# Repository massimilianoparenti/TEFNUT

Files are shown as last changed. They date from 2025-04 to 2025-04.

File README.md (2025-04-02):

# TEFNUT
Open-source, low-power temperature, humidity, and VOC sensor with E-Ink display and LoRa connectivity. Battery-powered and designed for both indoor and outdoor use, this device is ideal for smart homes, IoT applications, and environmental monitoring. Easy deployment, high efficiency, and full customization.

**DESCRIPTION**

This project aims to create a simple, low-power temperature, humidity, and VOC sensor with long-range connectivity. At its core, it features an E-Ink display for excellent readability even in direct sunlight, while LoRa communication ensures seamless integration with home automation systems and other IoT applications.

Powered by a battery, this device is built for versatility and easy deployment in both indoor and outdoor environments. It focuses on efficiency and simplicity to provide an accessible and practical solution for monitoring temperature, humidity, air quality, and gas presence.

Best of all, it’s fully open source—anyone can modify, improve, or adapt it to their needs.

If this sounds interesting, stay tuned for updates!

**REPOSITORY MAP**

**CONTRIBUTORS**

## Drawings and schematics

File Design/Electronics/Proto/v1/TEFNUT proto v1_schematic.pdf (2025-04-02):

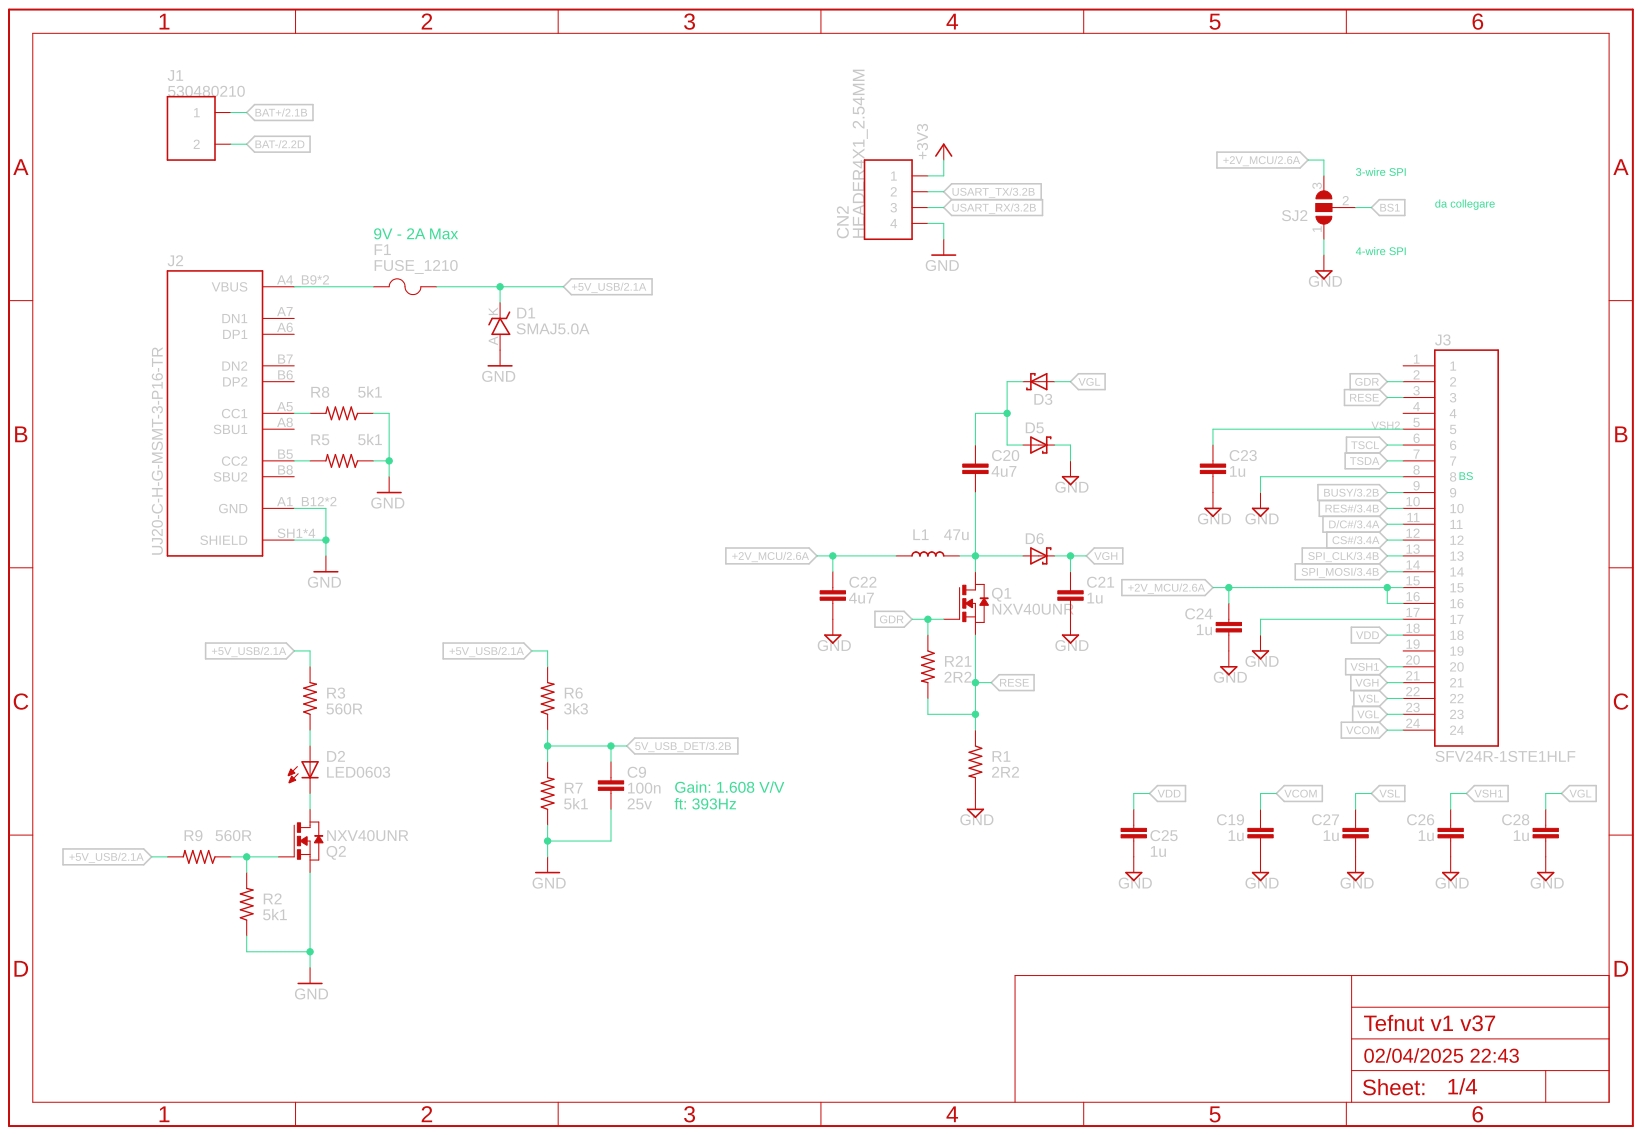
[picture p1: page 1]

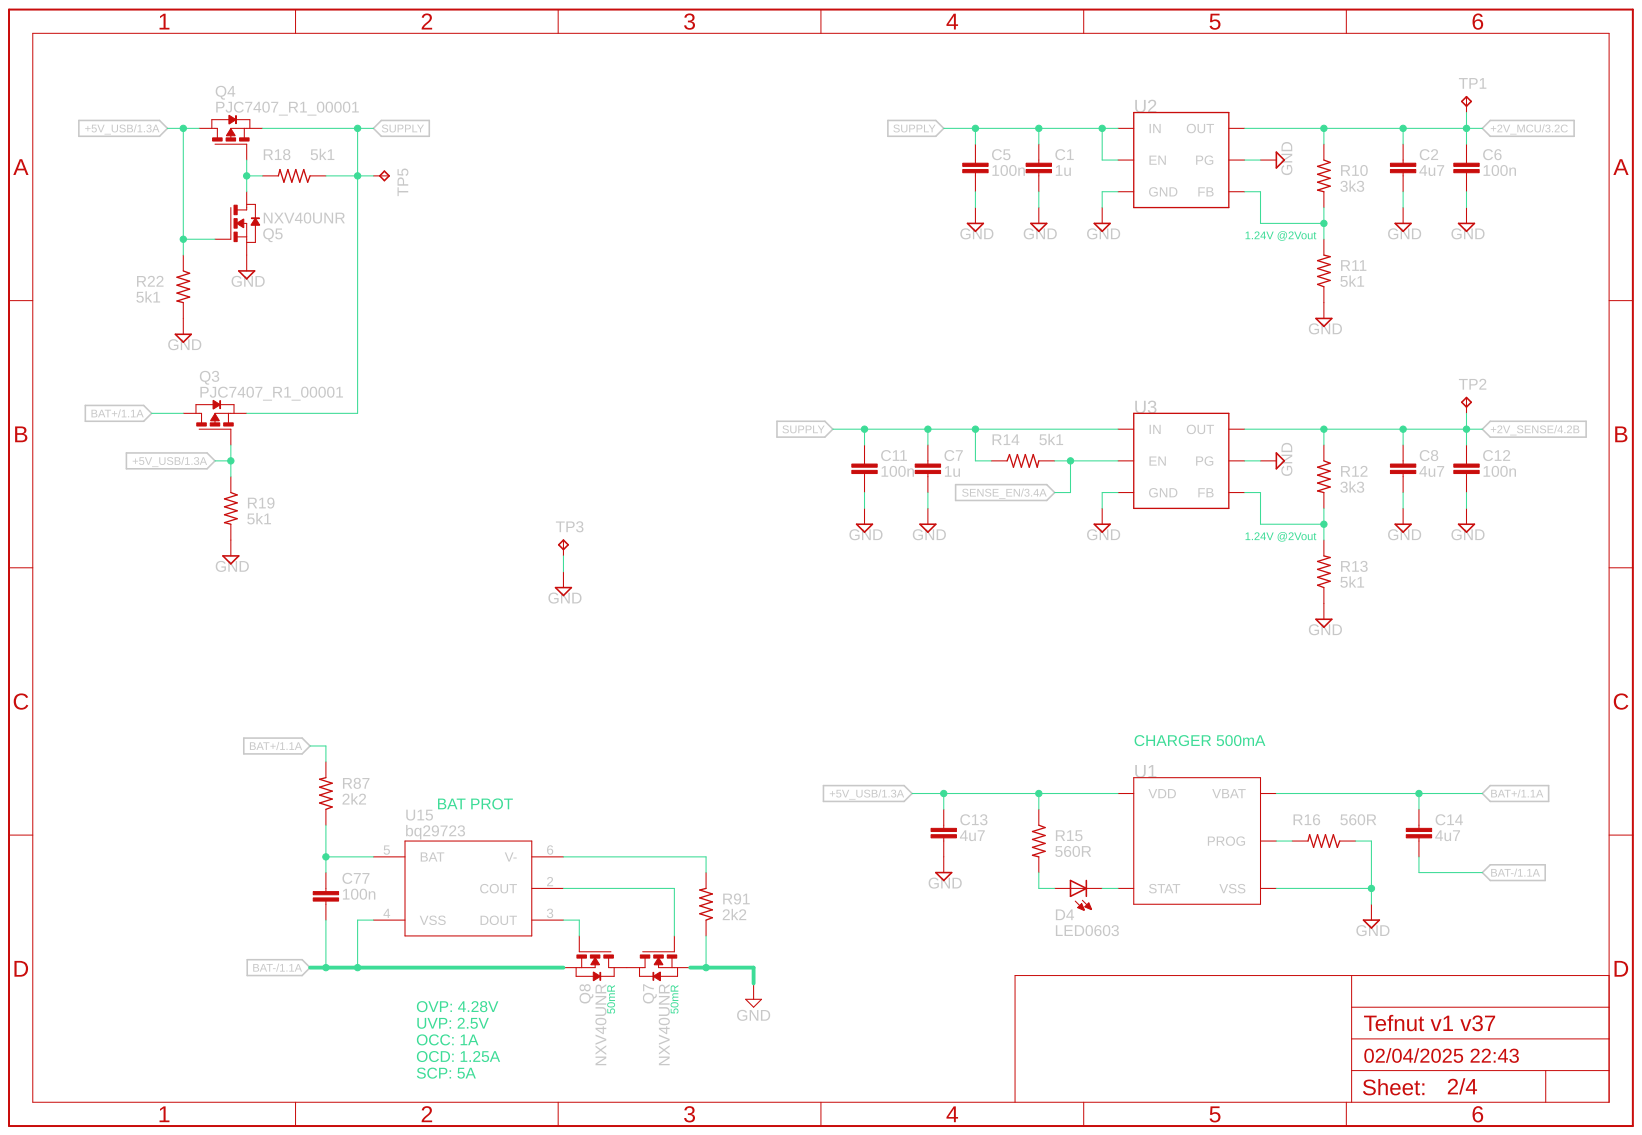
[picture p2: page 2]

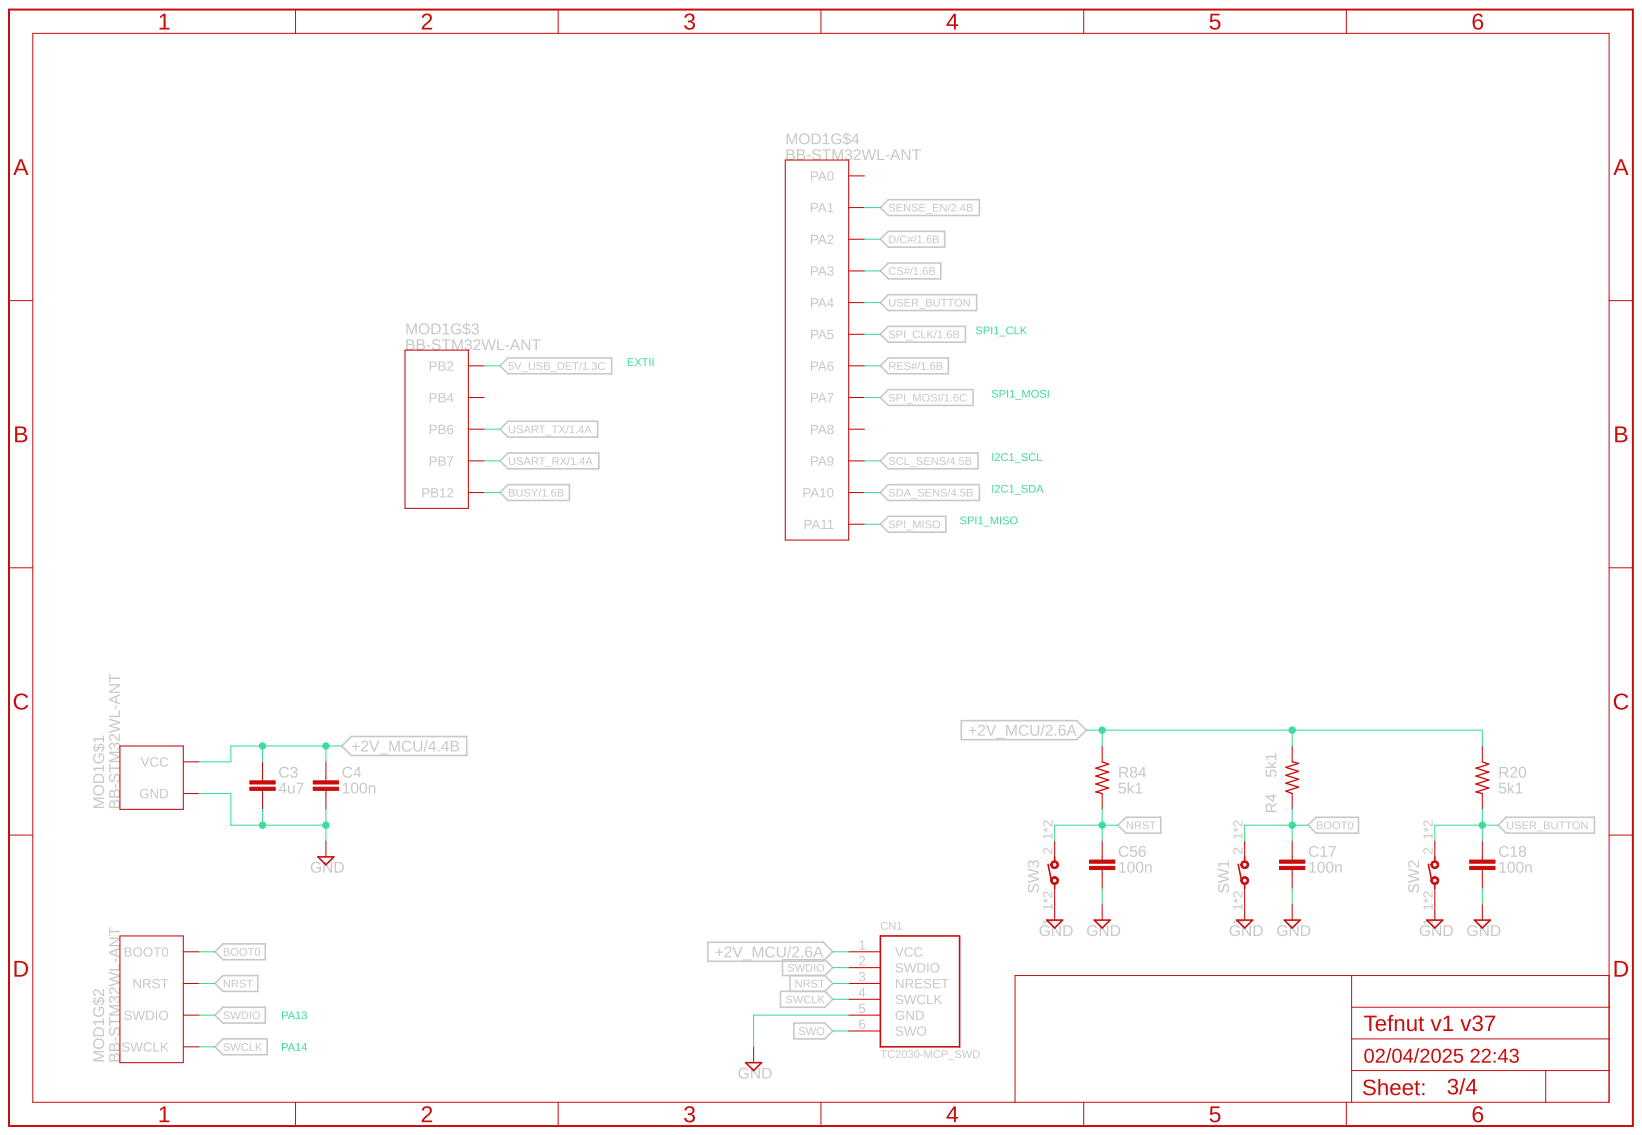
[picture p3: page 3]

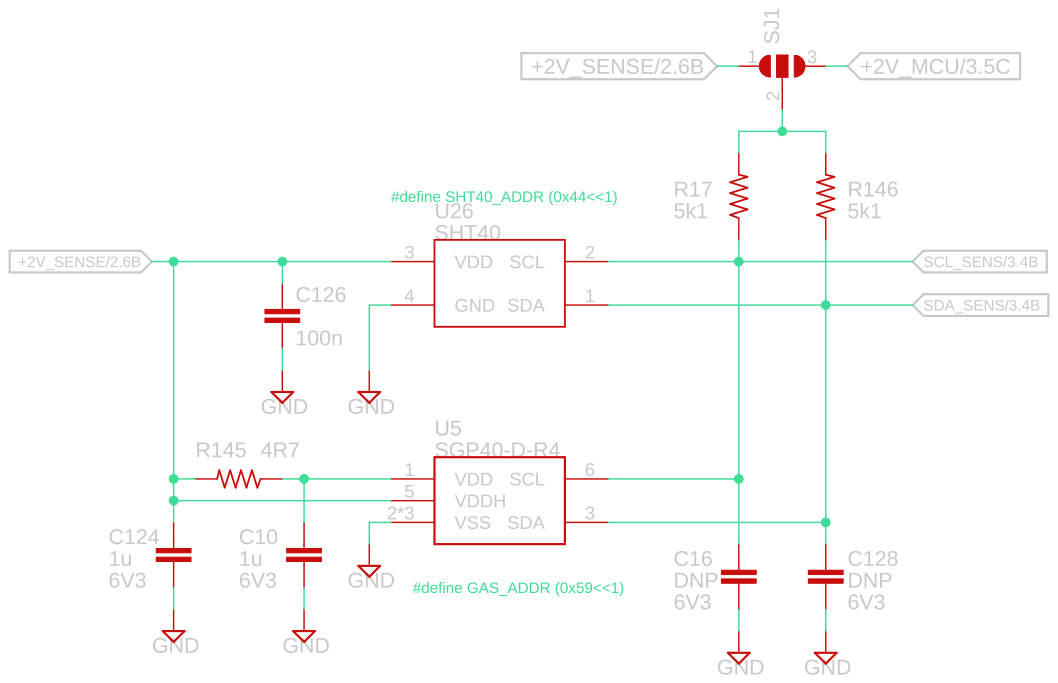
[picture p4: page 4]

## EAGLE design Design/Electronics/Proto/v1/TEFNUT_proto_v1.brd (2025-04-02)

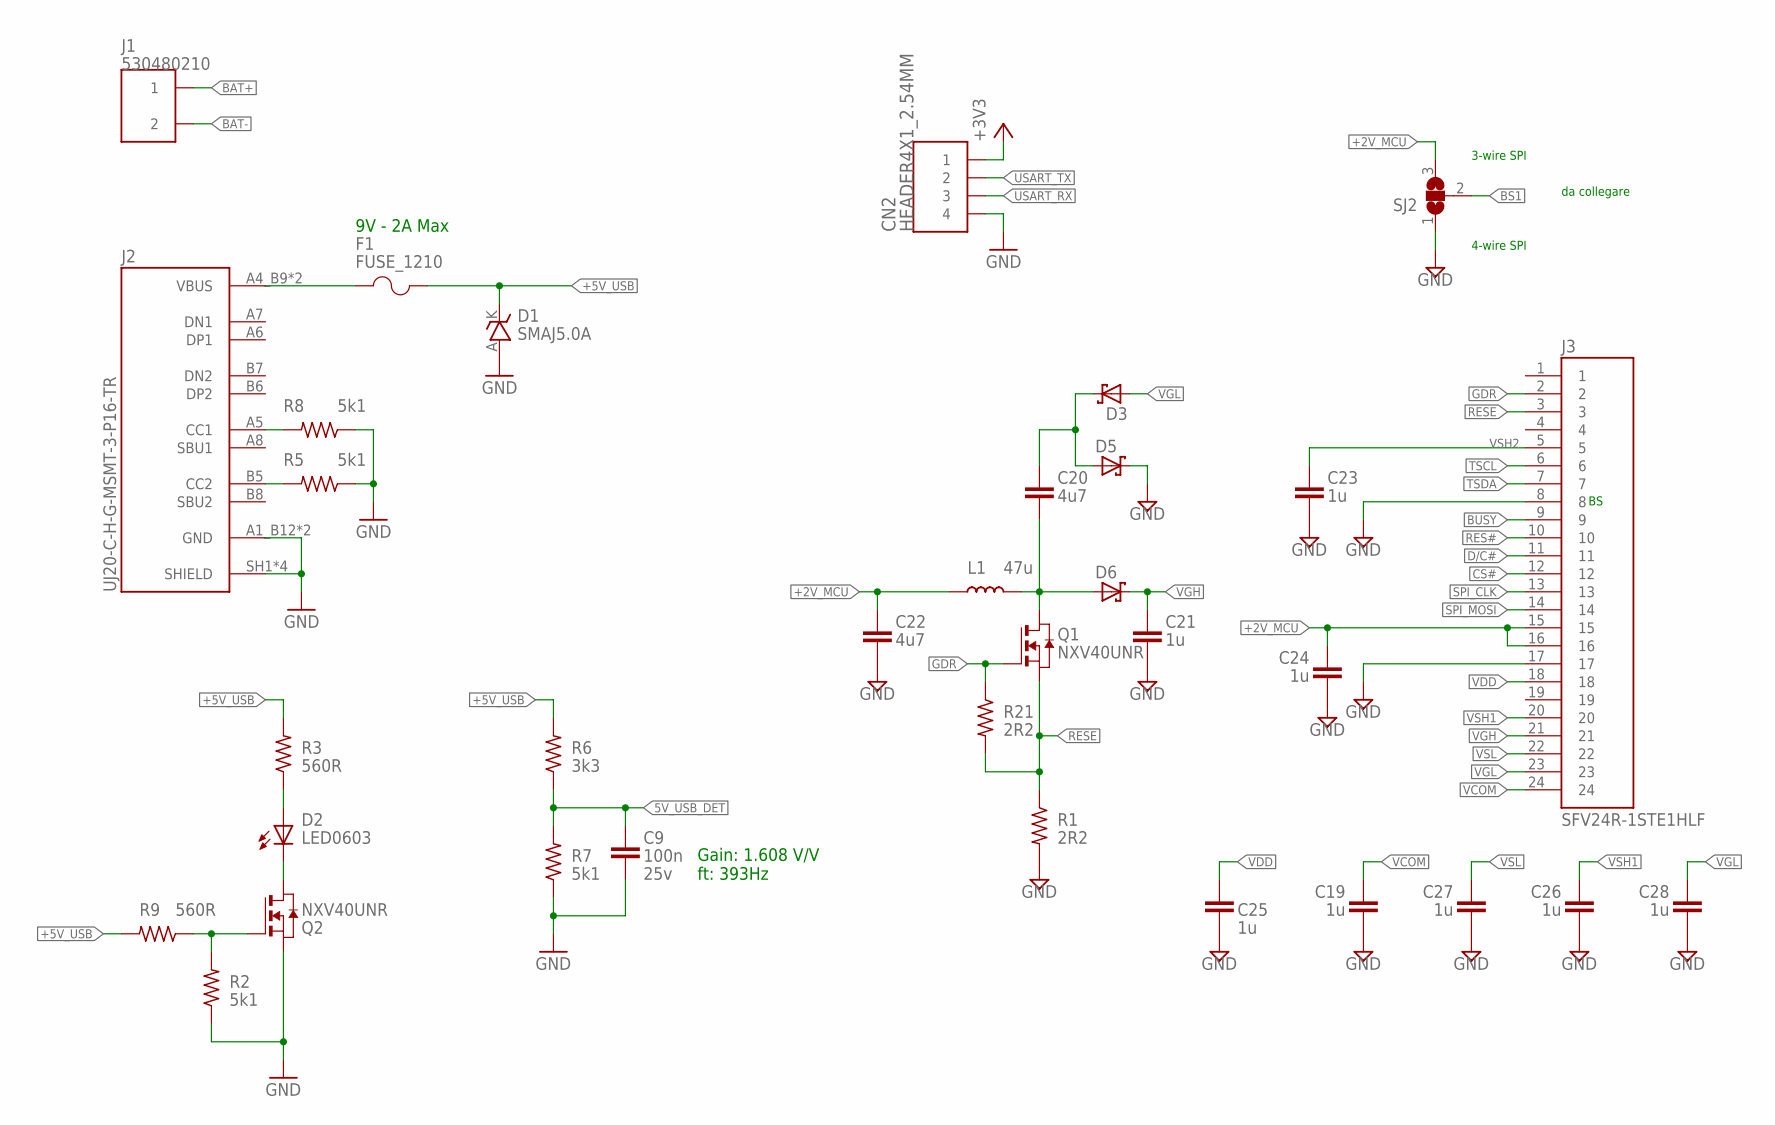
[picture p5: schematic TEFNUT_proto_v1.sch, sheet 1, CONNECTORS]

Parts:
C9: 100n; C0603[1608]; PARTNO CL10B104KO8NNNC
C19, C21, C23, C24, C25, C26, C27, C28: 1u; C0603[1608]; PARTNO CL10A105KO8NNNC
C20, C22: 4u7; C0603[1608]; PARTNO CL10A475KO8NNNC
CN2: HEADER4X1_2.54MM
D1: TVS214AC; DO-214AC; PARTNO SMAJ5.0A
D2: LED0603
D3, D5, D6: SCHOTTKY_DIODE_SOD123; SOD123; PARTNO MBR0530
F1: FUSE_1210; R1210[3225]; PARTNO SMD1210B110TF/16
J1: 530480210; PARTNO 530480210
J2: UJ20-C-H-G-MSMT-3-P16-TR; SAMESKY_UJ20-C-H-G-MSMT-3-P16-TR; PARTNO UJ20-C-H-G-MSMT-3-P16
J3: SFV24R-1STE1HLF; AMPHENOL_SFV24R-1STE1HLF; PARTNO SFV24R-1STE1HLF
L1: 47u; L0805[2012]; PARTNO MLF2012E100JT000
Q1, Q2: NXV40UNR; SOT23-3; PARTNO NXV40UNR
R1, R21: 2R2; R0603; PARTNO ERJ-U03F2R20V
R2, R5, R7, R8: 5k1; R0603; PARTNO RC0603FR-075K1L
R3, R9: 560R; R0603; PARTNO RC0603FR-07560RL
R6: 3k3; R0603; PARTNO RC0603FR-073K3L
SJ2: SJ2W; SJ_2

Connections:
5V_USB_DET: C9.1, R6.1, R7.2; also elsewhere on the board
+2V_MCU: C22.1, C24.1, J3.15, J3.16, L1.1, SJ2.3; also elsewhere on the board
+3V3: CN2.1
+5V_USB: D1.K, F1.2, R3.2, R6.2, R9.2; also elsewhere on the board
BAT+: J1.1; also elsewhere on the board
BAT-: J1.2; also elsewhere on the board
BS1: SJ2.2
BUSY: J3.9; also elsewhere on the board
CS#: J3.12; also elsewhere on the board
D/C#: J3.11; also elsewhere on the board
GDR: J3.2, Q1.1 (G), R21.1
GND: C9.2, C19.2, C21.2, C22.2, C23.2, C24.2, C25.2, C26.2, C27.2, C28.2, CN2.4, D1.A, D5.K, J2.A1_B12 (GND), J2.B1_A12 (GND), J2.SH1 (SHIELD), J2.SH2 (SHIELD), J2.SH3 (SHIELD), J2.SH4 (SHIELD), J3.8, J3.17, Q2.2 (S), R1.2, R2.1, R5.1, R7.1, R8.1, SJ2.1; also elsewhere on the board
unnamed: D2.2 (K), Q2.3 (D)
unnamed: D2.1 (A), R3.1
unnamed: J2.A5 (CC1), R8.2
unnamed: J2.B5 (CC2), R5.2
unnamed: F1.1, J2.A4_B9 (VBUS), J2.B4_A9 (VBUS)
unnamed: C20.1, D3.K, D5.A
unnamed: C20.2, D6.A, L1.2, Q1.3 (D)
unnamed: Q2.1 (G), R2.2, R9.1
RES#: J3.10; also elsewhere on the board
RESE: J3.3, Q1.2 (S), R1.1, R21.2
SPI_CLK: J3.13; also elsewhere on the board
SPI_MOSI: J3.14; also elsewhere on the board
TSCL: J3.6
TSDA: J3.7
USART_RX: CN2.3; also elsewhere on the board
USART_TX: CN2.2; also elsewhere on the board
VCOM: C19.1, J3.24
VDD: C25.1, J3.18
VGH: C21.1, D6.K, J3.21
VGL: C28.1, D3.A, J3.23
VSH1: C26.1, J3.20
VSH2: C23.1, J3.5
VSL: C27.1, J3.22

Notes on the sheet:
Gain: 1.608 V/V ft: 393Hz
9V - 2A Max
4-wire SPI
3-wire SPI
da collegare

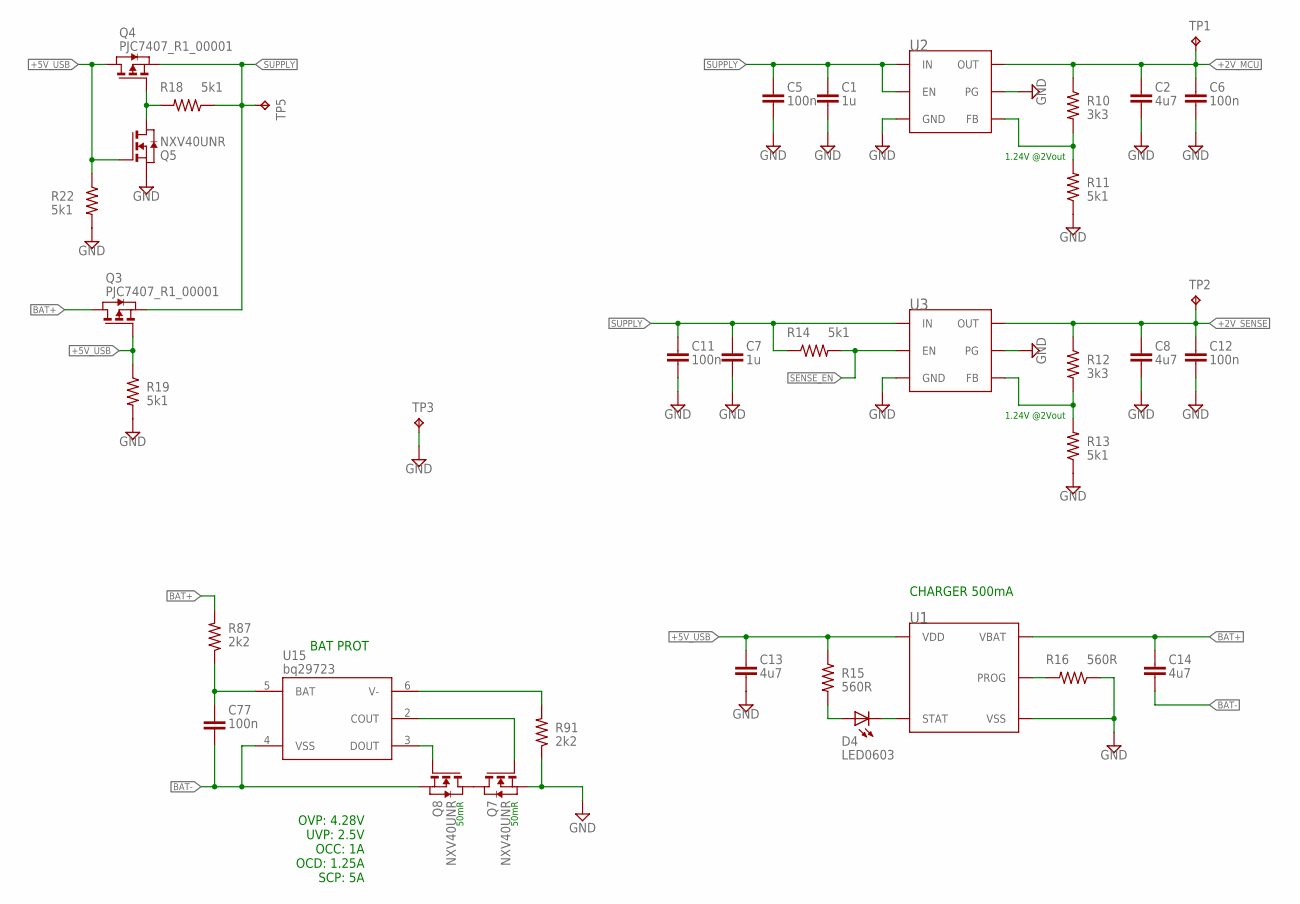
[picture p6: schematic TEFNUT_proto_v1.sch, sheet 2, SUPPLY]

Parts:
C1, C7: 1u; C0603[1608]; PARTNO CL10A105KO8NNNC
C2, C8: 4u7; C0603[1608]; PARTNO CL10A475KO8NNNC
C5, C6, C11, C12, C77: 100n; C0603[1608]; PARTNO CL10B104KO8NNNC
C13, C14: 4u7; C0805[2012]; PARTNO CL21A475KOFNNNE
D4: LED0603
Q3, Q4: PJC7407_R1_00001; SOT323-3(SC-70-3); PARTNO PJC7407_R1_00001
Q5, Q7, Q8: NXV40UNR; SOT23-3; PARTNO NXV40UNR
R10, R12: 3k3; R0603; PARTNO RC0603FR-073K3L
R11, R13, R14: 5k1; R0603; PARTNO RC0603FR-075K1L
R15, R16: 560R; R0603; PARTNO RC0603FR-07560RL
R18, R19, R22: 5k1; R0603[1608]; PARTNO RC0603FR-075K1L
R87, R91: 2k2; R0603; PARTNO ERJ-3EKF2201V
TP1, TP2, TP3, TP5: TPB1,27; B1,27
U1: MCP73831T; SOT23-5; PARTNO MCP73831T-2DCI/OT
U2, U3: TPS7A2501DRVRDRV0006A-IPC_B; 6-WDFN; PARTNO TPS7A2501DRVR
U15: bq29723; WSON6; PARTNO BQ29704DSER

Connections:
+2V_MCU: C2.1, C6.1, R10.1, TP1.TP, U2.1 (OUT); also elsewhere on the board
+2V_SENSE: C8.1, C12.1, R12.1, TP2.TP, U3.1 (OUT); also elsewhere on the board
+5V_USB: C13.1, Q3.1 (G), Q4.3 (D), Q5.1 (G), R15.1, R19.1, R22.1, U1.4 (VDD); also elsewhere on the board
BAT+: C14.1, Q3.3 (D), R87.2, U1.3 (VBAT); also elsewhere on the board
BAT-: C14.2, C77.2, Q8.2 (S), U15.4 (VSS); also elsewhere on the board
GND: C1.2, C2.2, C5.2, C6.2, C7.2, C8.2, C11.2, C12.2, C13.2, Q5.2 (S), Q7.2 (S), R11.1, R13.1, R16.1, R19.2, R22.2, R91.1, TP3.TP, U1.2 (VSS), U2.3 (PG), U2.5 (GND), U2.7 (GND), U3.3 (PG), U3.5 (GND), U3.7 (GND); also elsewhere on the board
unnamed: C77.1, R87.1, U15.5 (BAT)
unnamed: D4.1 (A), R15.2
unnamed: R10.2, R11.2, U2.2 (FB)
unnamed: R12.2, R13.2, U3.2 (FB)
unnamed: R16.2, U1.5 (PROG)
unnamed: D4.2 (K), U1.1 (STAT)
unnamed: Q4.1 (G), Q5.3 (D), R18.2
unnamed: R91.2, U15.6 (V-)
unnamed: Q7.3 (D), Q8.3 (D)
unnamed: Q7.1 (G), U15.2 (COUT)
unnamed: Q8.1 (G), U15.3 (DOUT)
SENSE_EN: R14.2, U3.4 (EN); also elsewhere on the board
SUPPLY: C1.1, C5.1, C7.1, C11.1, Q3.2 (S), Q4.2 (S), R14.1, R18.1, TP5.TP, U2.4 (EN), U2.6 (IN), U3.6 (IN)

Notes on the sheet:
OVP: 4.28V UVP: 2.5V OCC: 1A OCD: 1.25A SCP: 5A
1.24V @2Vout
BAT PROT
CHARGER 500mA
50mR

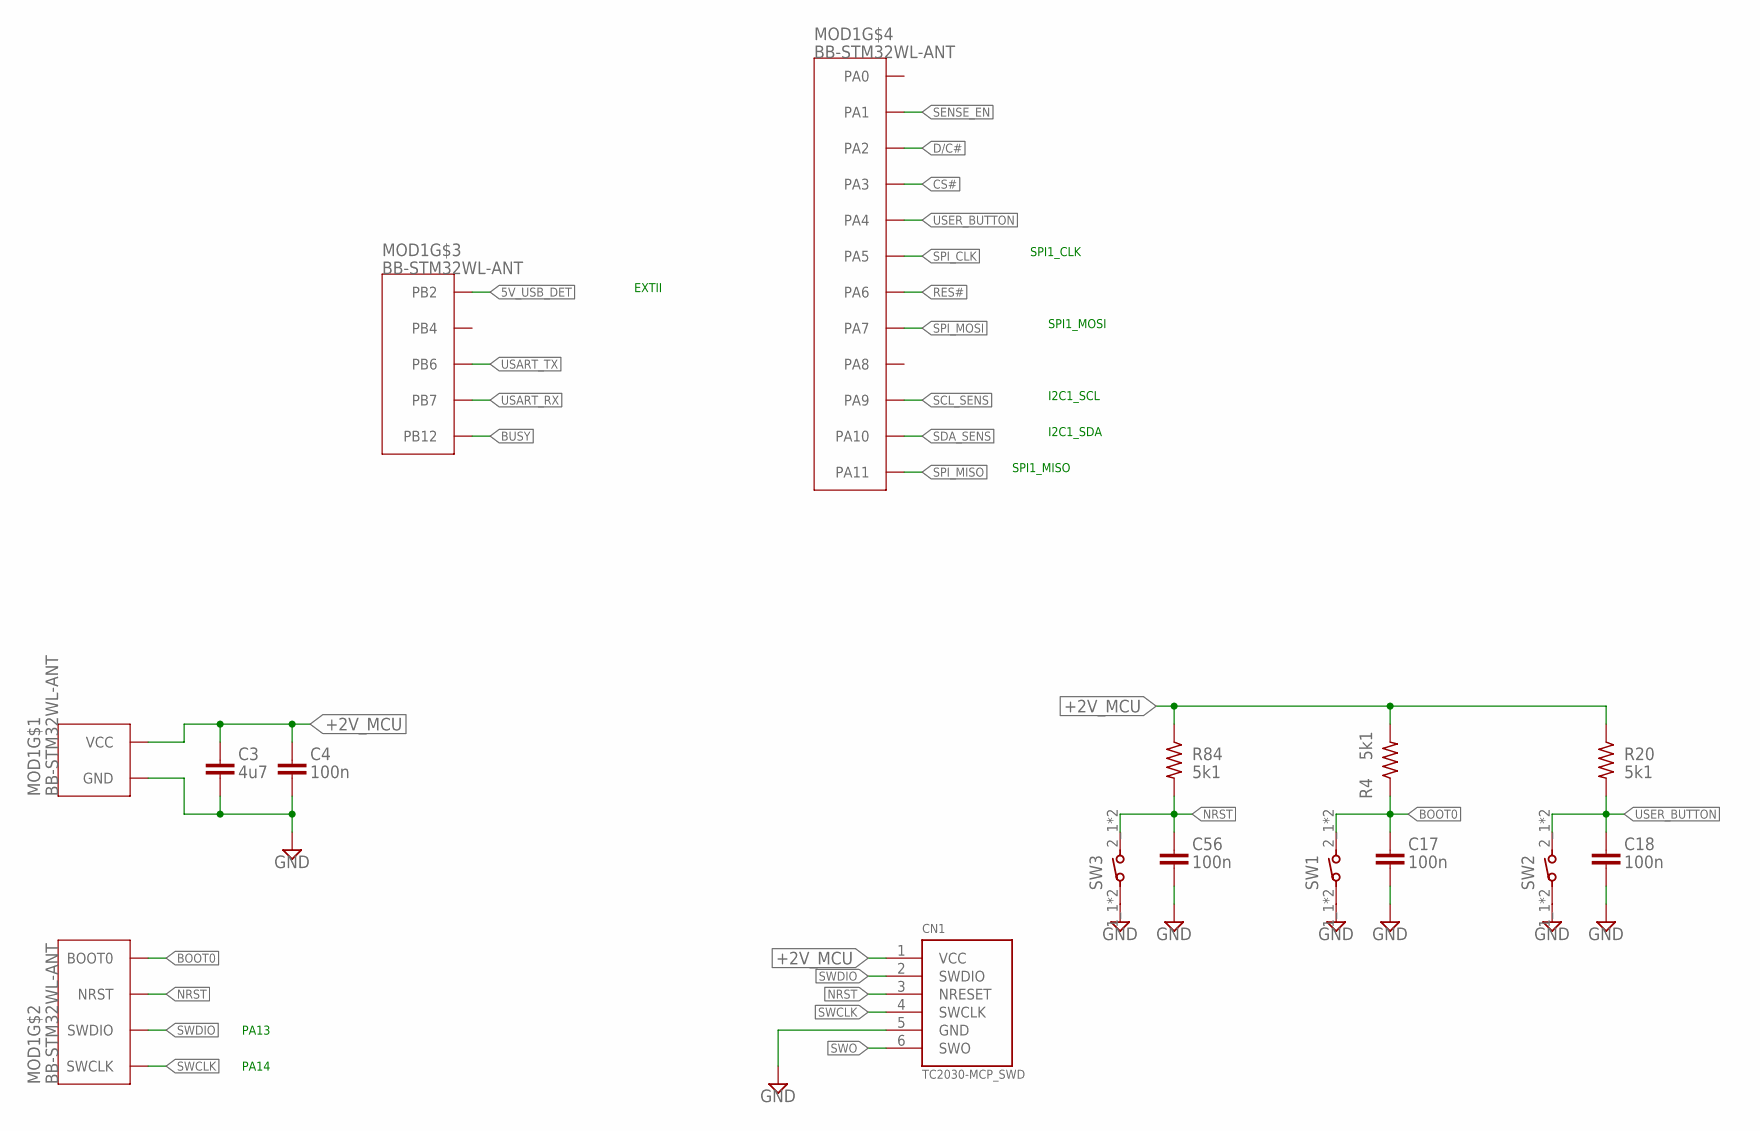
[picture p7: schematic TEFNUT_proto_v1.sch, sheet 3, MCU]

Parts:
C3: 4u7; C0805[2012]; PARTNO CL21A475KOFNNNE
C4: 100n; C0805[2012]; PARTNO CC0805KRX7R7BB104
C17, C18, C56: 100n; C0603[1608]; PARTNO CL10B104KO8NNNC
CN1: TC2030-MCP_SWD; TC2030-IDC
MOD1: BB-STM32WL-ANT
R4, R20, R84: 5k1; R0603; PARTNO RC0603FR-075K1L
SW1, SW2, SW3: SWITCHEVQ_4PIN; EVQ-P7L01P; PARTNO EVQP7L01P

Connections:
5V_USB_DET: MOD1.PB2; also elsewhere on the board
+2V_MCU: C3.1, C4.1, CN1.1 (VCC), MOD1.VCC, R4.2, R20.1, R84.1; also elsewhere on the board
BOOT0: C17.1, MOD1.BOOT0, R4.1, SW1.2_1 (2), SW1.2_2 (2)
BUSY: MOD1.PB12; also elsewhere on the board
CS#: MOD1.PA3; also elsewhere on the board
D/C#: MOD1.PA2; also elsewhere on the board
GND: C3.2, C4.2, C17.2, C18.2, C56.2, CN1.5 (GND), MOD1.GND, MOD1.GND@2 (GND), SW1.1_1 (1), SW1.1_2 (1), SW2.1_1 (1), SW2.1_2 (1), SW3.1_1 (1), SW3.1_2 (1); also elsewhere on the board
NRST: C56.1, CN1.3 (NRESET), MOD1.NRST, R84.2, SW3.2_1 (2), SW3.2_2 (2)
RES#: MOD1.PA6; also elsewhere on the board
SCL_SENS: MOD1.PA9; also elsewhere on the board
SDA_SENS: MOD1.PA10; also elsewhere on the board
SENSE_EN: MOD1.PA1; also elsewhere on the board
SPI_CLK: MOD1.PA5; also elsewhere on the board
SPI_MISO: MOD1.PA11
SPI_MOSI: MOD1.PA7; also elsewhere on the board
SWCLK: CN1.4 (SWCLK), MOD1.SWCLK
SWDIO: CN1.2 (SWDIO), MOD1.SWDIO
SWO: CN1.6 (SWO)
USART_RX: MOD1.PB7; also elsewhere on the board
USART_TX: MOD1.PB6; also elsewhere on the board
USER_BUTTON: C18.1, MOD1.PA4, R20.2, SW2.2_1 (2), SW2.2_2 (2)

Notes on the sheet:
I2C1_SCL
I2C1_SDA
SPI1_MISO
SPI1_MOSI
SPI1_CLK
EXTII
PA14
PA13

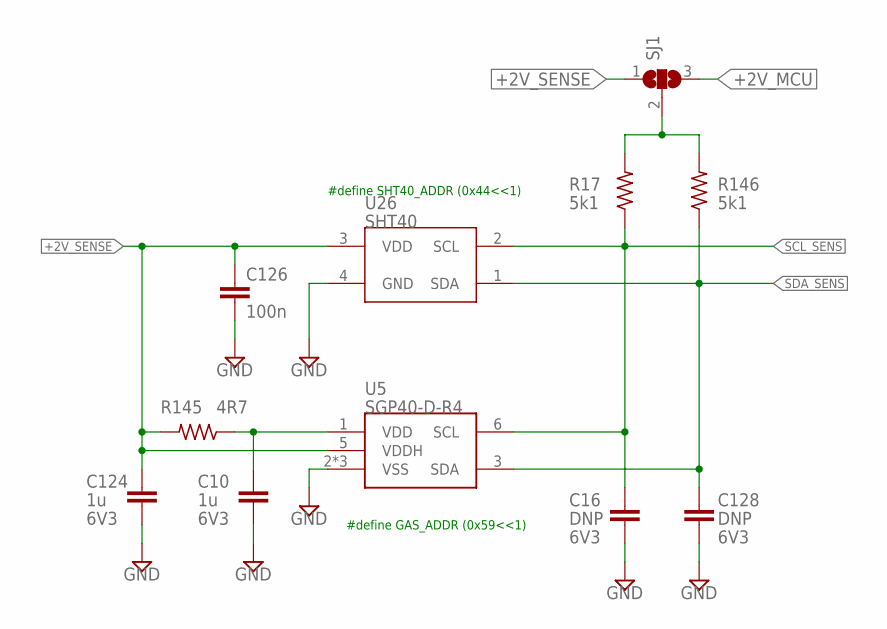
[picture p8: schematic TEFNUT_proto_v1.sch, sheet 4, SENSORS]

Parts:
C10, C124: 1u; C0603[1608]; PARTNO CL10A105KO8NNNC
C16, C128: DNP; C0603[1608]; PARTNO *
C126: 100n; C0603[1608]; PARTNO CL10B104KO8NNNC
R17, R146: 5k1; R0603[1608]; PARTNO RC0603FR-075K1L
R145: 4R7; R0603; PARTNO AC0603FR-072R2L
SJ1: SJ2W; SJ_2
U5: SGP40-D-R4; DFN6; PARTNO SGP40-D-R4
U26: SHT40; SH4X; PARTNO SHT40-AD1B-R3

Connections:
+2V_MCU: SJ1.3; also elsewhere on the board
+2V_SENSE: C124.2, C126.1, R145.2, SJ1.1, U5.5 (VDDH), U26.3 (VDD); also elsewhere on the board
GND: C10.1, C16.1, C124.1, C126.2, C128.1, U5.2 (VSS), U5.4 (VSS), U5.7 (VSS), U26.4 (GND); also elsewhere on the board
unnamed: R17.2, R146.2, SJ1.2
unnamed: C10.2, R145.1, U5.1 (VDD)
SCL_SENS: C16.2, R17.1, U5.6 (SCL), U26.2 (SCL); also elsewhere on the board
SDA_SENS: C128.2, R146.1, U5.3 (SDA), U26.1 (SDA); also elsewhere on the board

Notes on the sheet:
#define SHT40_ADDR (0x44<<1)
#define GAS_ADDR (0x59<<1)

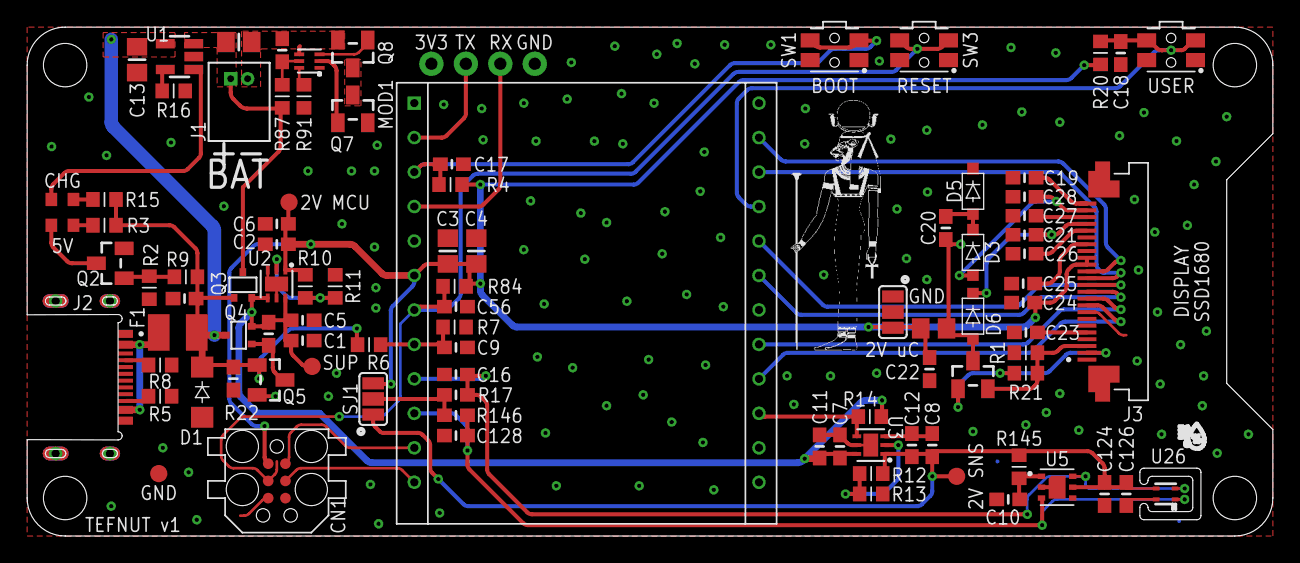
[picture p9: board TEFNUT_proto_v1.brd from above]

Board: 2 copper layers, 91.8 x 37.5 mm, 95 parts (0 on the bottom side), 54 nets.

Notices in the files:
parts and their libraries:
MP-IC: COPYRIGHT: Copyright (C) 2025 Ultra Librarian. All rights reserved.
